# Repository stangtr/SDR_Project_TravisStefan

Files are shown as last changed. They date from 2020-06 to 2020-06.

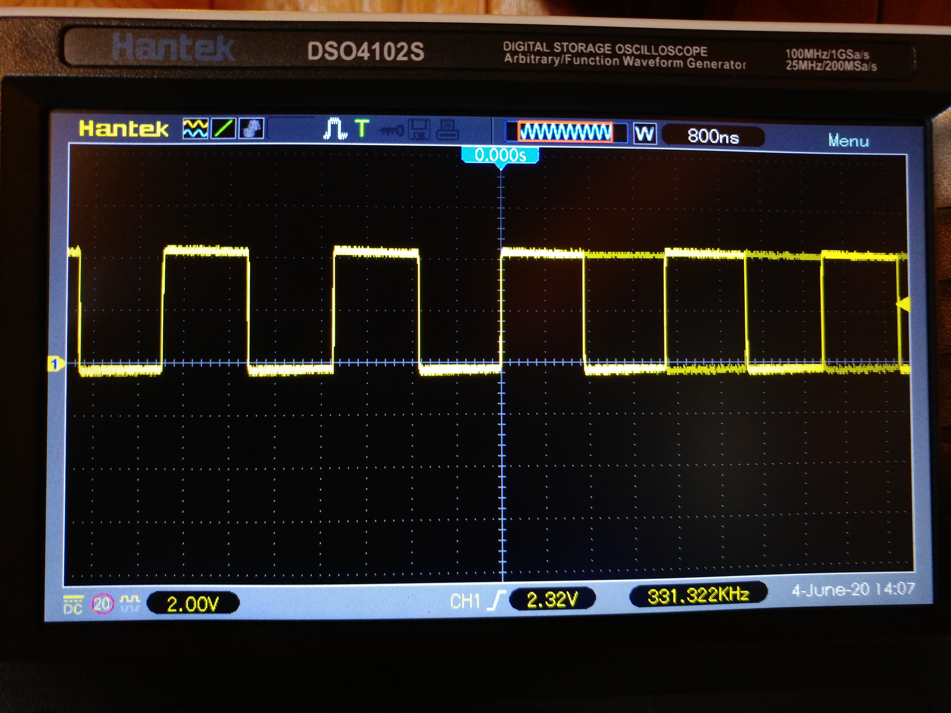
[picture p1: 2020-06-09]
Images/OscilloscopeImages_TravisS/I_LO_NoJumper.jpg

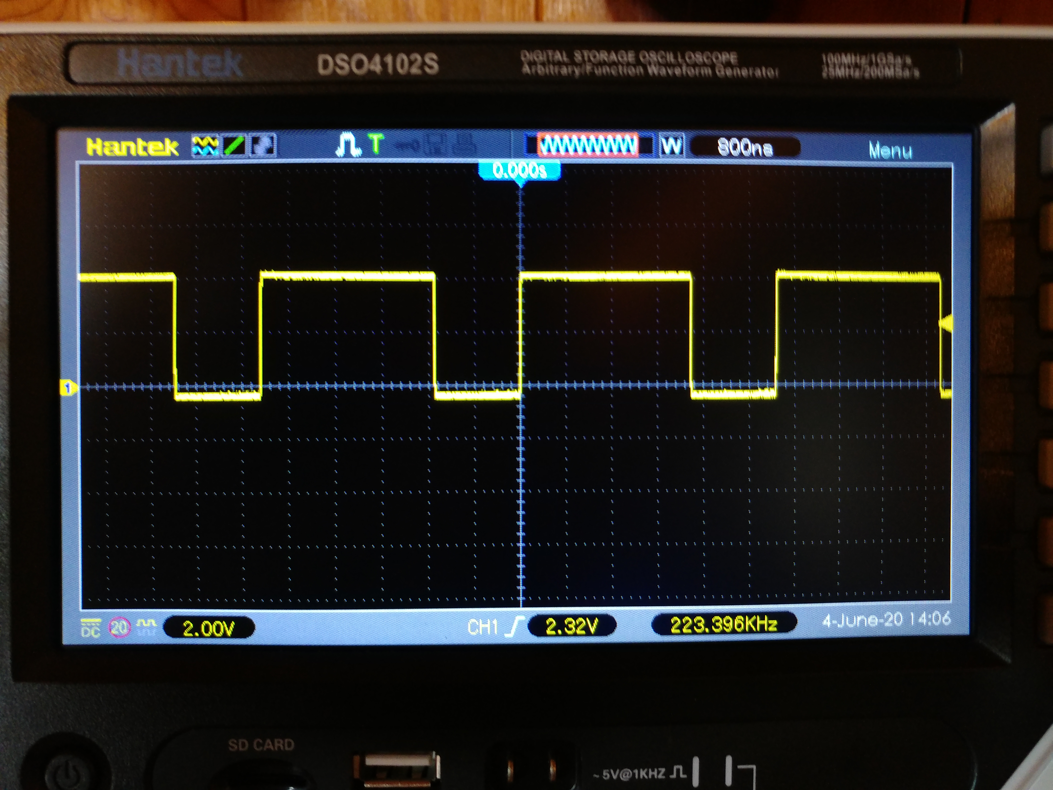
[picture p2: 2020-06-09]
Images/OscilloscopeImages_TravisS/Q_LO_NoJumper.jpg

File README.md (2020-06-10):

# SDR_Project_TravisStefan

## Project Overview
The goal of this project was to design a Software Defined Reciever (SDR) for ENGR 357 Electronics II at Walla Walla University.
Our receiver is designed for the AM frequency range (535kHz - 1605kHz).
Before designing the board in KiCad, we did some simulations in LTSpice to find the correct values for resistors and capacitors, as well as inductors for the band-pass filter (BPF).

## Finished Product
Ideally, the SDR board would have a signal input to the female SMA connector on the input of the BPF. This signal would then be processed and sent to the computer via an auxiliary cable. The correct frequency could be tuned to using the Quisk open radio software. An Arduino is connected to the board for powering the ICs and setting the correct clock output on the Si5351 oscillator IC through communication with Quisk or a short test program. 

## More Documentation
More details can be viewed about the process and the specifications in the wiki tab.

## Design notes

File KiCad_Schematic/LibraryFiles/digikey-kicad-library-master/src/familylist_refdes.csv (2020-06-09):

205 | Embedded - Microcontrollers | U
275 | Motion Sensors - Accelerometers | U
1152 | Magnetic Sensors - Linear, Compass (ICs) | U
69 | TVS - Diodes | D
19 | Fixed Inductors | L
793 | Interface - Controllers | U
1373 | PMIC - Battery Chargers | U
748 | Optical Sensors - Ambient Light, IR, UV Sensors | U
366 | Oscillators | Y
707 | RF Detectors | U
446 | Data Acquisition - Digital Potentiometers | U
533 | Logic - Translators, Level Shifters | U
1324 | Diodes - Bridge Rectifiers | D
740 | USB, DVI, HDMI Connectors | J
1379 | Motion Sensors - IMUs (Inertial Measurement Units) | U
1303 | Barrel - Audio Connectors | CON
628 | Humidity, Moisture Sensors | U
51 | Encoders | S
71 | Alarms, Buzzers, and Sirens | BZ
94 | Tactile Switches | S
968 | Optical Sensors - Photodiodes | PV
120 | Transistors - Bipolar (BJT) - Single | Q
706 | Transistors - Bipolar (BJT) - RF | Q
386 | PMIC - Voltage Regulators - Linear | U
72 | Microphones | MIC
872 | Signal Relays, Up to 2 Amps | RLY
1193 | Memory Connectors - PC Card Sockets | J
40 | Infrared, UV, Visible Emitters | D
655 | Gas Sensors | U
973 | Optical Sensors - Photointerrupters - Slot Type - Logic Output | U
61 | Fuses | F
125 | Transistors - FETs, MOSFETs - Single | Q
79 | Programmable Oscillators | Y
311 | Temperature Sensors - Analog and Digital Output | U
1398 | Automotive Relays | RLY
1400 | Reed Relays | RLY
421 | Logic - Multivibrators | U
127 | Diodes - Rectifiers - Single | D
778 | Diodes - Zener - Single | Z
758 | Diodes - Rectifiers - Arrays | D
210 | Specialized ICs | U
293 | PMIC - Supervisors | U
319 | PMIC - Voltage Reference | VR
747 | Transistors - FETs, MOSFETs - RF | Q
1010 | Transistors - Bipolar (BJT) - Single, Pre-Biased | Q
544 | PMIC - Current Regulation/Management | U
804 | PMIC - Power Management - Specialized | U
1004 | RF Transceiver Modules | MOD
838 | Transistors - FETs, MOSFETs - Arrays | Q
404 | Logic - Buffers, Drivers, Receivers, Transceivers | U
711 | RF Switches | U
122 | Transistors - Bipolar (BJT) - Arrays | Q
1281 | Slide Switches | S
413 | Logic - Gates and Inverters | U
502 | PMIC - Power Distribution Switches, Load Drivers | U
523 | PMIC - Gate Drivers | U
221 | Linear - Amplifiers - Instrumentation, OP Amps, Buffer Amps | U
317 | Linear - Comparators | U
724 | PMIC - LED Drivers | U
388 | Data Acquisition - Digital to Analog Converters (DAC) | U
666 | PMIC - Voltage Regulators - DC DC Switching Regulators | U
865 | TVS - Mixed Technology | TVS
700 | RF Evaluation and Development Kits, Boards | A
1344 | Rotary Potentiometers, Rheostats | POT
871 | Power Relays, Over 2 Amps | RLY
948 | Modular Connectors - Jacks | J
1306 | Coaxial Connectors (RF) | J
944 | Optical Sensors - Photo Detectors - Remote Receiver | U
683 | Ferrite Beads and Chips | FB
441 | LED Indication - Discrete | D
969 | Optical Sensors - Phototransistors | Q
674 | Image Sensors, Camera | U
420 | Interface - Drivers, Receivers, Transceivers | U
100 | Toggle Switches | S
36 | Display Modules - LED Character and Numeric | DS
387 | Data Acquisition - Analog to Digital Converters (ADC) | U
517 | Clock/Timing - Clock Generators, PLLs, Frequency Synthesizers | U
432 | PMIC - Battery Management | U
34 | Battery Holders, Clips, Contacts | BAT
1127 | Surge Suppression ICs | U
438 | PMIC - Voltage Regulators - DC DC Switching Controllers | U
656 | PMIC - Thermal Management | U
1370 | Interface - Analog Switches - Special Purpose | U
789 | PMIC - Voltage Regulators - Special Purpose | U
728 | PMIC - Full, Half-Bridge Drivers | U
422 | Logic - Shift Registers | U
515 | PMIC - V/F and F/V Converters | U
414 | Logic - Flip Flops | U
679 | Linear - Amplifiers - Audio | U
722 | PMIC - Motor Drivers, Controllers | U
767 | Interface - Analog Switches, Multiplexers, Demultiplexers | U
831 | Optoisolators - Transistor, Photovoltaic Output | U
786 | Interface - I/O Expanders | U
1002 | RF Receivers | U
1349 | RF Transceiver ICs | U
691 | Logic - Signal Switches, Multiplexers, Decoders | U
1357 | RFID, RF Access, Monitoring ICs | U
88 | Solid State Relays | RLY
972 | Optical Sensors - Reflective - Analog Output | U
829 | Optoisolators - Logic Output | U
842 | Optoisolators - Triac, SCR Output | U
75 | Balun | T
226 | Clock/Timing - Programmable Timers and Oscillators | U
266 | Clock/Timing - Real Time Clocks | U
668 | PMIC - RMS to DC Converters | U
179 | Pressure Sensors, Transducers | U
552 | Digital Isolators | U
792 | Interface - Sensor and Detector Interfaces | U
1076 | Memory | U
493 | Current Transducers | U
768 | PMIC - AC DC Converters, Offline Switchers | U
800 | PMIC - OR Controllers, Ideal Diodes | Q
7 | Resistor Networks, Arrays | RN
64 | Thyristors - DIACs, SIDACs | D
97 | Pushbutton Switches | S
1140 | Magnetic Sensors - Compass, Magnetic Field (Modules) | U
725 | Navigation Switches, Joystick | S
336 | Thermal Cutoffs (Thermal Fuses) | F
448 | LEDs - Circuit Board Indicators, Arrays, Light Bars, Bar Graphs | D
1315 | Specialized Sensors | U
84 | Accessories | NA
824 | Trimmer Potentiometers | POT
131 | Thyristors - SCRs | D
1325 | Thyristors - TRIACs | TRI
1366 | Magnetic Sensors - Switches (Solid State) | Q
837 | Transistors - JFETs | Q
1003 | RF Transmitters | U
1360 | Addressable, Specialty | D
755 | Rectangular Connectors - Headers, Male Pins | J
947 | Modular Connectors - Jacks With Magnetics | J
913 | Inrush Current Limiters (ICL) | ICL
1230 | Data Acquisition - Touch Screen Controllers | U
1293 | Capacitive Touch Sensors, Proximity Sensor ICs | U
1176 | RF Demodulators | U
223 | DC DC Converters | U
461 | Motion Sensors - Tilt Switches | S
864 | Data Acquisition - ADCs/DACs - Special Purpose | U
1295 | Interface - Modules | U
703 | RF Amplifiers | U
1078 | RF Antennas | ANT
1180 | Sockets for ICs, Transistors | J
1308 | D-Sub Connectors | J
794 | Interface - Specialized | U
1117 | Evaluation Boards - Sensors | A
333 | Evaluation Boards - Embedded - MCU, DSP | A
630 | Display Modules - LCD, OLED, Graphic | DS
365 | Crystal | XTAL
135 | Banana and Tip Connectors - Jacks, Plugs | J
1304 | Barrel - Power Connectors | J
946 | Optical Sensors - Distance Measuring | U
168 | Shunts, Jumpers | J
586 | Test Points | TP
959 | Terminal Blocks - Wire to Board | J

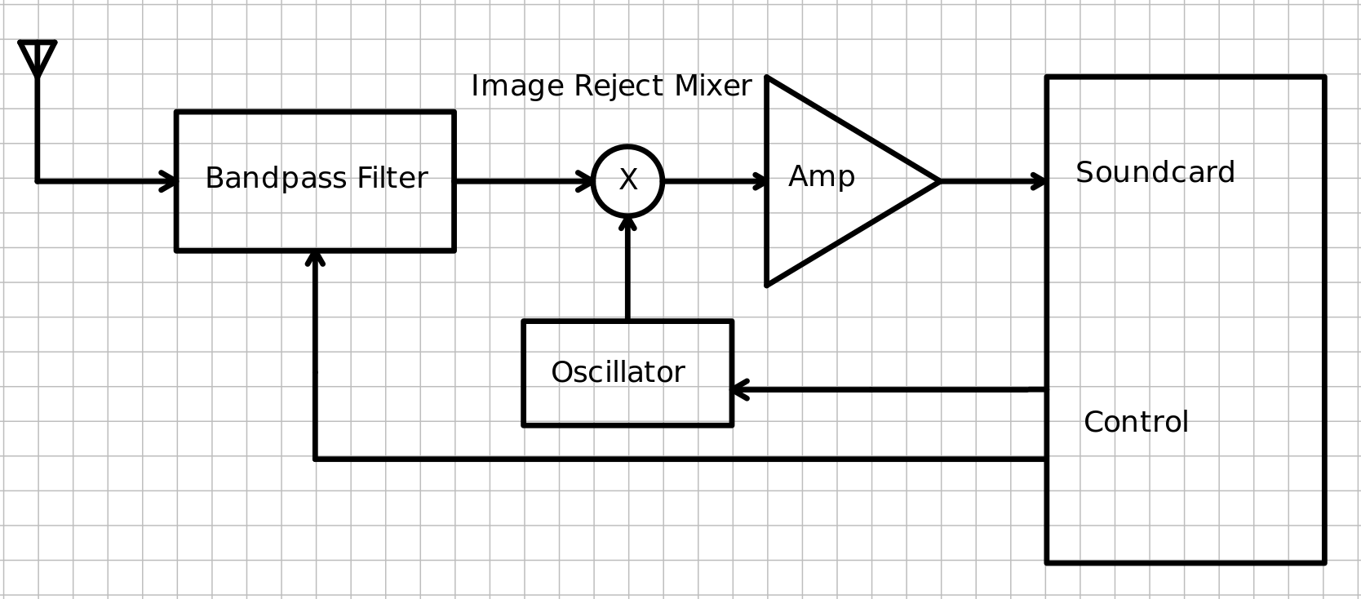
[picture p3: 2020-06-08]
Images/BlockDiagram.png

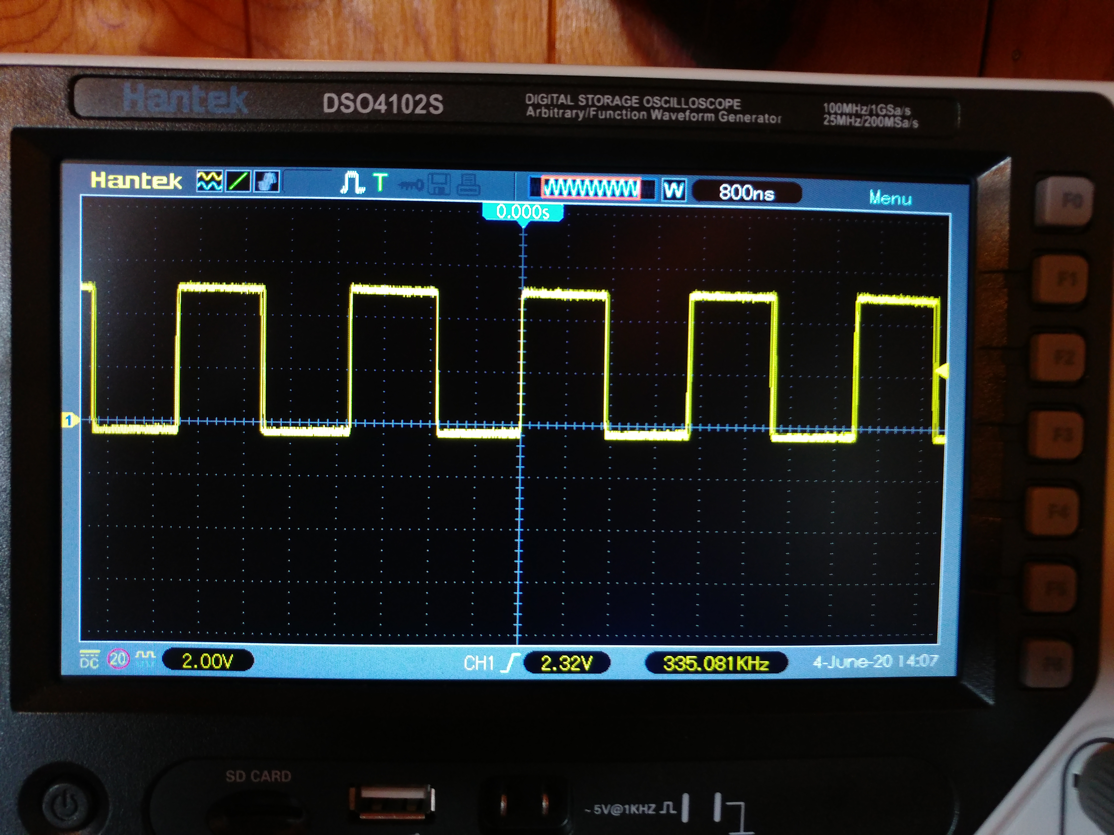
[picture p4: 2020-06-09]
Images/OscilloscopeImages_TravisS/I_LO_WithJumper.jpg

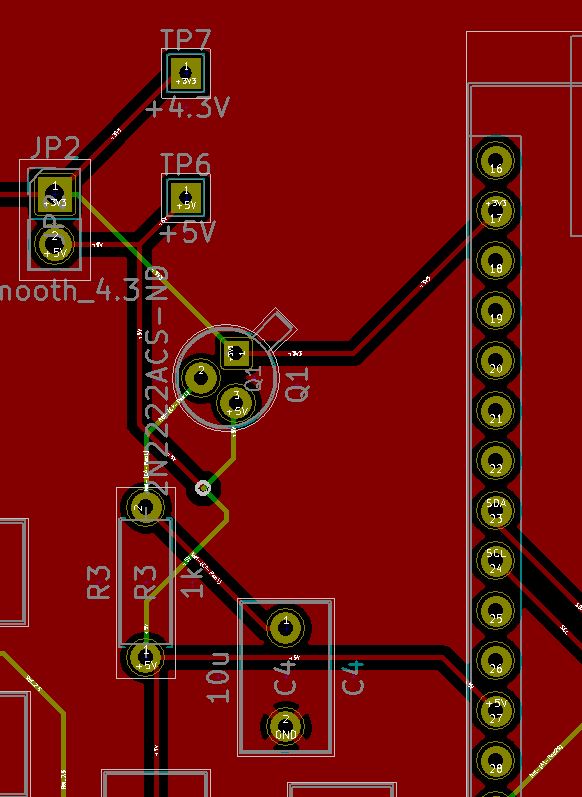
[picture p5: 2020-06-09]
Images/BJT_PCB_Error.JPG

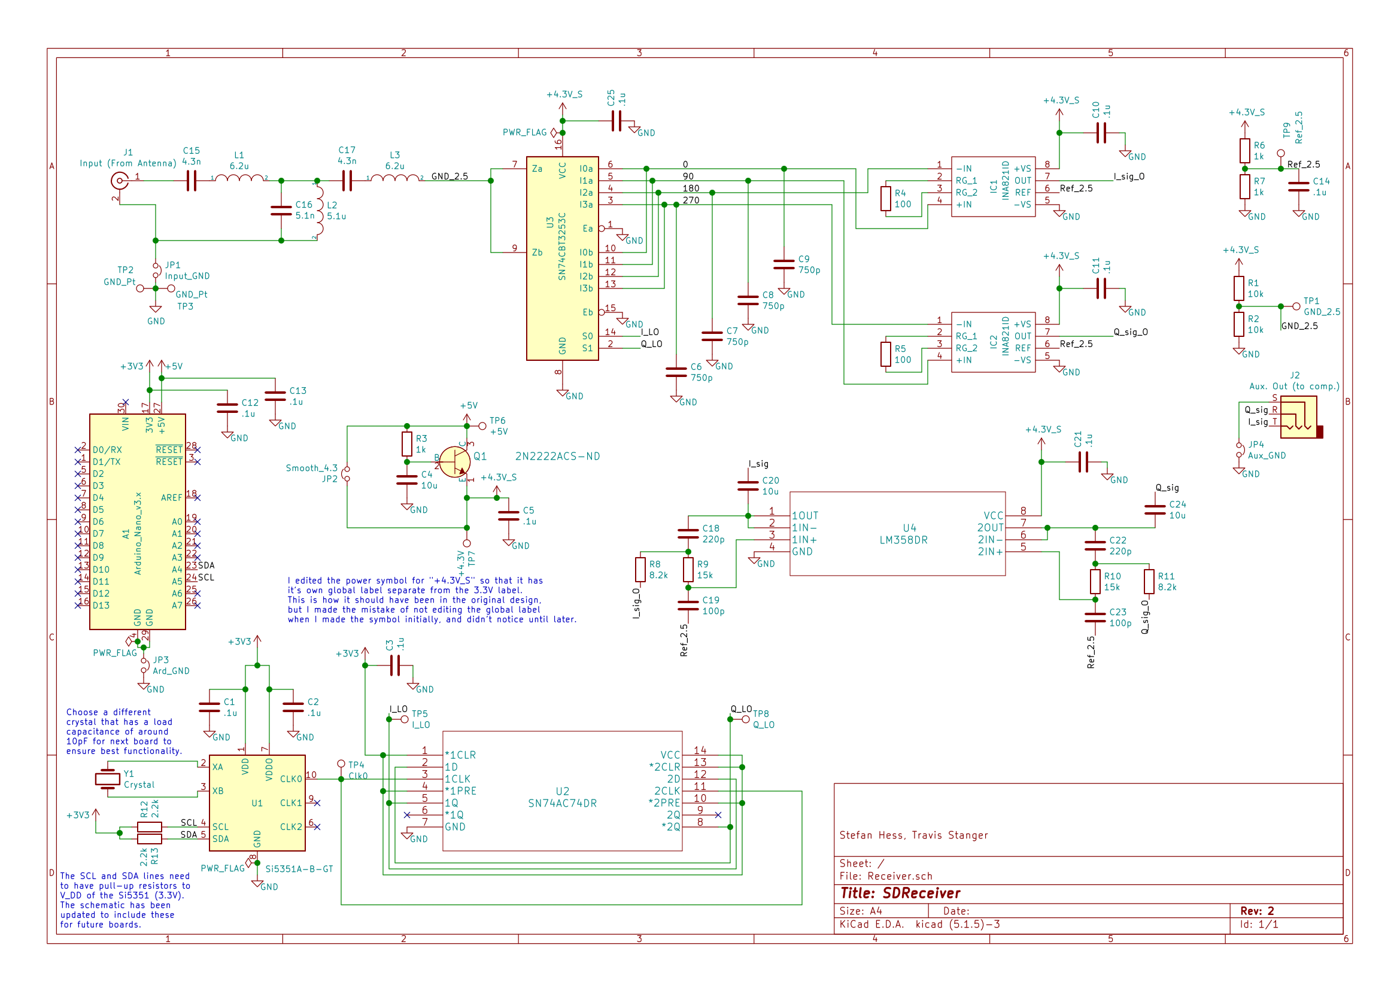
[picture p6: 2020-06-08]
Images/NewReceiver.png

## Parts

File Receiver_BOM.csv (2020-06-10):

Reference | Value | Footprint | Datasheet | Description | Height | Manufacturer_Name | Manufacturer_Part_Number | Mouser Part Number | Mouser Price/Stock
A1 | Arduino_Nano_v3.x | Module:Arduino_Nano | http://www.mouser.com/pdfdocs/Gravitech_Arduino_Nano3_0.pdf
C01 | .1u | Capacitor_THT:C_Disc_D16.0mm_W5.0mm_P10.00mm | http://datasheets.avx.com/SR-Series.pdf
C02 | .1u | Capacitor_THT:C_Disc_D16.0mm_W5.0mm_P10.00mm | http://datasheets.avx.com/SR-Series.pdf
C03 | .1u | Capacitor_THT:C_Disc_D16.0mm_W5.0mm_P10.00mm | http://datasheets.avx.com/SR-Series.pdf
C04 | 10u | Capacitor_THT:C_Disc_D7.5mm_W4.4mm_P5.00mm | https://www.digikey.com/en/datasheets/tdk-corporation/tdk-corporation-leadmlcc-conventional-fk-en
C05 | .1u | Capacitor_THT:C_Disc_D16.0mm_W5.0mm_P10.00mm | http://datasheets.avx.com/SR-Series.pdf
C06 | 750p | Capacitor_THT:C_Disc_D7.5mm_W5.0mm_P7.50mm | https://www.nteinc.com/capacitor_web/pdf/90000.pdf
C07 | 750p | Capacitor_THT:C_Disc_D7.5mm_W5.0mm_P7.50mm | https://www.nteinc.com/capacitor_web/pdf/90000.pdf
C08 | 750p | Capacitor_THT:C_Disc_D7.5mm_W5.0mm_P7.50mm | https://www.nteinc.com/capacitor_web/pdf/90000.pdf
C09 | 750p | Capacitor_THT:C_Disc_D7.5mm_W5.0mm_P7.50mm | https://www.nteinc.com/capacitor_web/pdf/90000.pdf
C10 | .1u | Capacitor_THT:C_Disc_D16.0mm_W5.0mm_P10.00mm | http://datasheets.avx.com/SR-Series.pdf
C11 | .1u | Capacitor_THT:C_Disc_D16.0mm_W5.0mm_P10.00mm | http://datasheets.avx.com/SR-Series.pdf
C12 | .1u | Capacitor_THT:C_Disc_D16.0mm_W5.0mm_P10.00mm | http://datasheets.avx.com/SR-Series.pdf
C13 | .1u | Capacitor_THT:C_Disc_D16.0mm_W5.0mm_P10.00mm | http://datasheets.avx.com/SR-Series.pdf
C14 | .1u | Capacitor_THT:C_Disc_D16.0mm_W5.0mm_P10.00mm | http://datasheets.avx.com/SR-Series.pdf
C15 | 4.3n | Capacitor_SMD:C_0603_1608Metric_Pad1.05x0.95mm_HandSolder | https://search.murata.co.jp/Ceramy/image/img/A01X/G101/ENG/GRM1887U1H432JA01-01.pdf
C16 | 5.1n | Capacitor_SMD:C_0603_1608Metric_Pad1.05x0.95mm_HandSolder | https://search.murata.co.jp/Ceramy/image/img/A01X/G101/ENG/GRM1887U1H512JA01-01.pdf
C17 | 4.3n | Capacitor_SMD:C_0603_1608Metric_Pad1.05x0.95mm_HandSolder | https://search.murata.co.jp/Ceramy/image/img/A01X/G101/ENG/GRM1887U1H432JA01-01.pdf
C18 | 220p | Capacitor_THT:C_Disc_D7.5mm_W5.0mm_P7.50mm | https://content.kemet.com/datasheets/KEM_C1049_GOLDMAX_C0G.pdf
C19 | 100p | Capacitor_THT:C_Disc_D7.5mm_W5.0mm_P7.50mm | https://content.kemet.com/datasheets/KEM_C1049_GOLDMAX_C0G.pdf
C20 | 10u | Capacitor_THT:C_Disc_D7.5mm_W4.4mm_P5.00mm | https://www.digikey.com/en/datasheets/tdk-corporation/tdk-corporation-leadmlcc-conventional-fk-en
C21 | .1u | Capacitor_THT:C_Disc_D16.0mm_W5.0mm_P10.00mm | http://datasheets.avx.com/SR-Series.pdf
C22 | 220p | Capacitor_THT:C_Disc_D7.5mm_W5.0mm_P7.50mm | https://content.kemet.com/datasheets/KEM_C1049_GOLDMAX_C0G.pdf
C23 | 100p | Capacitor_THT:C_Disc_D7.5mm_W5.0mm_P7.50mm | https://content.kemet.com/datasheets/KEM_C1049_GOLDMAX_C0G.pdf
C24 | 10u | Capacitor_THT:C_Disc_D7.5mm_W4.4mm_P5.00mm | https://www.digikey.com/en/datasheets/tdk-corporation/tdk-corporation-leadmlcc-conventional-fk-en
C25 | .1u | Capacitor_THT:C_Disc_D16.0mm_W5.0mm_P10.00mm | http://datasheets.avx.com/SR-Series.pdf
IC1 | INA821ID | digikey-footprints:SOIC-8_W3.9mm | http://www.ti.com/lit/ds/symlink/ina821.pdf | Instrumentation Amplifiers Precision Low Power INA | 1.75 | Texas Instruments | INA821ID | 595-INA821ID | https://www.mouser.com/Search/Refine.aspx?Keyword=595-INA821ID
IC2 | INA821ID | digikey-footprints:SOIC-8_W3.9mm | http://www.ti.com/lit/ds/symlink/ina821.pdf | Instrumentation Amplifiers Precision Low Power INA | 1.75 | Texas Instruments | INA821ID | 595-INA821ID | https://www.mouser.com/Search/Refine.aspx?Keyword=595-INA821ID
J1 | Input (From Antenna) | Connector_Coaxial:SMA_Molex_73251-1153_EdgeMount_Horizontal | ~
J2 | Aux. Out (to comp.) | Connector_Audio:Jack_3.5mm_Switronic_ST-005-G_horizontal | ~
JP1 | Input_GND | Connector_PinHeader_2.54mm:PinHeader_1x02_P2.54mm_Vertical | ~
JP2 | Smooth_4.3 | Connector_PinHeader_2.54mm:PinHeader_1x02_P2.54mm_Vertical | ~
JP3 | Ard_GND | Connector_PinHeader_2.54mm:PinHeader_1x02_P2.54mm_Vertical | ~
JP4 | Aux_GND | Connector_PinHeader_2.54mm:PinHeader_1x02_P2.54mm_Vertical | ~
L1 | 6.2u | Inductor_THT:L_Toroid_Vertical_L10.0mm_W5.0mm_P5.08mm | http://www.lodestonepacific.com/distrib/pdfs/Micrometals/RFA_Cat.pdf
L2 | 5.1u | Inductor_THT:L_Toroid_Vertical_L10.0mm_W5.0mm_P5.08mm | http://www.lodestonepacific.com/distrib/pdfs/Micrometals/RFA_Cat.pdf
L3 | 6.2u | Inductor_THT:L_Toroid_Vertical_L10.0mm_W5.0mm_P5.08mm | http://www.lodestonepacific.com/distrib/pdfs/Micrometals/RFA_Cat.pdf
Q1 | 2N2222ACS-ND | digikey-footprints:TO-18-3 | https://my.centralsemi.com/get_document.php?cmp=1&mergetype=pd&mergepath=pd&pdf_id=2N2221A.PDF
R01 | 10k | Resistor_THT:R_Axial_DIN0207_L6.3mm_D2.5mm_P7.62mm_Horizontal | ~
R02 | 10k | Resistor_THT:R_Axial_DIN0207_L6.3mm_D2.5mm_P7.62mm_Horizontal | ~
R03 | 1k | Resistor_THT:R_Axial_DIN0207_L6.3mm_D2.5mm_P7.62mm_Horizontal | ~
R04 | 100 | Resistor_THT:R_Axial_DIN0207_L6.3mm_D2.5mm_P7.62mm_Horizontal | ~
R05 | 100 | Resistor_THT:R_Axial_DIN0207_L6.3mm_D2.5mm_P7.62mm_Horizontal | ~
R06 | 1k | Resistor_THT:R_Axial_DIN0207_L6.3mm_D2.5mm_P7.62mm_Horizontal | ~
R07 | 1k | Resistor_THT:R_Axial_DIN0207_L6.3mm_D2.5mm_P7.62mm_Horizontal | ~
R08 | 8.2k | Resistor_THT:R_Axial_DIN0207_L6.3mm_D2.5mm_P7.62mm_Horizontal | ~
R09 | 15k | Resistor_THT:R_Axial_DIN0207_L6.3mm_D2.5mm_P7.62mm_Horizontal | ~
R10 | 15k | Resistor_THT:R_Axial_DIN0207_L6.3mm_D2.5mm_P7.62mm_Horizontal | ~
R11 | 8.2k | Resistor_THT:R_Axial_DIN0207_L6.3mm_D2.5mm_P7.62mm_Horizontal | ~
R12 | 2.2k | Resistor_THT:R_Axial_DIN0207_L6.3mm_D2.5mm_P7.62mm_Horizontal | ~
R13 | 2.2k | Resistor_THT:R_Axial_DIN0207_L6.3mm_D2.5mm_P7.62mm_Horizontal | ~
TP1 | GND_2.5 | TestPoint:TestPoint_THTPad_1.5x1.5mm_Drill0.7mm | ~
TP2 | GND_Pt | TestPoint:TestPoint_THTPad_1.5x1.5mm_Drill0.7mm | ~
TP3 | GND_Pt | TestPoint:TestPoint_THTPad_1.5x1.5mm_Drill0.7mm | ~
TP4 | Clk0 | TestPoint:TestPoint_THTPad_1.5x1.5mm_Drill0.7mm | ~
TP5 | I_LO | TestPoint:TestPoint_THTPad_1.5x1.5mm_Drill0.7mm | ~
TP6 | +5V | TestPoint:TestPoint_THTPad_1.5x1.5mm_Drill0.7mm | ~
TP7 | +4.3V | TestPoint:TestPoint_THTPad_1.5x1.5mm_Drill0.7mm | ~
TP8 | Q_LO | TestPoint:TestPoint_THTPad_1.5x1.5mm_Drill0.7mm | ~
TP9 | Ref_2.5 | TestPoint:TestPoint_THTPad_1.5x1.5mm_Drill0.7mm | ~
U1 | Si5351A-B-GT | Package_SO:MSOP-10_3x3mm_P0.5mm | https://www.silabs.com/documents/public/data-sheets/Si5351-B.pdf
U2 | SN74AC74DR | digikey-footprints:SOIC-14_W3.9mm | https://www.ti.com/lit/ds/symlink/sn74ac74.pdf
U3 | SN74CBT3253C | Package_SO:SOIC-16_3.9x9.9mm_P1.27mm | https://www.ti.com/lit/ds/symlink/sn74cbt3253c.pdf?ts=1587934047839
U4 | LM358DR | digikey-footprints:SOIC-8_W3.9mm | https://www.ti.com/lit/ds/symlink/lm358.pdf?HQS=TI-null-null-digikeymode-df-pf-null-wwe
Y1 | Crystal | Crystal:Crystal_HC49-U_Vertical | http://www.raltron.com/wp-content/uploads/2016/12/AS-SERIES.pdf

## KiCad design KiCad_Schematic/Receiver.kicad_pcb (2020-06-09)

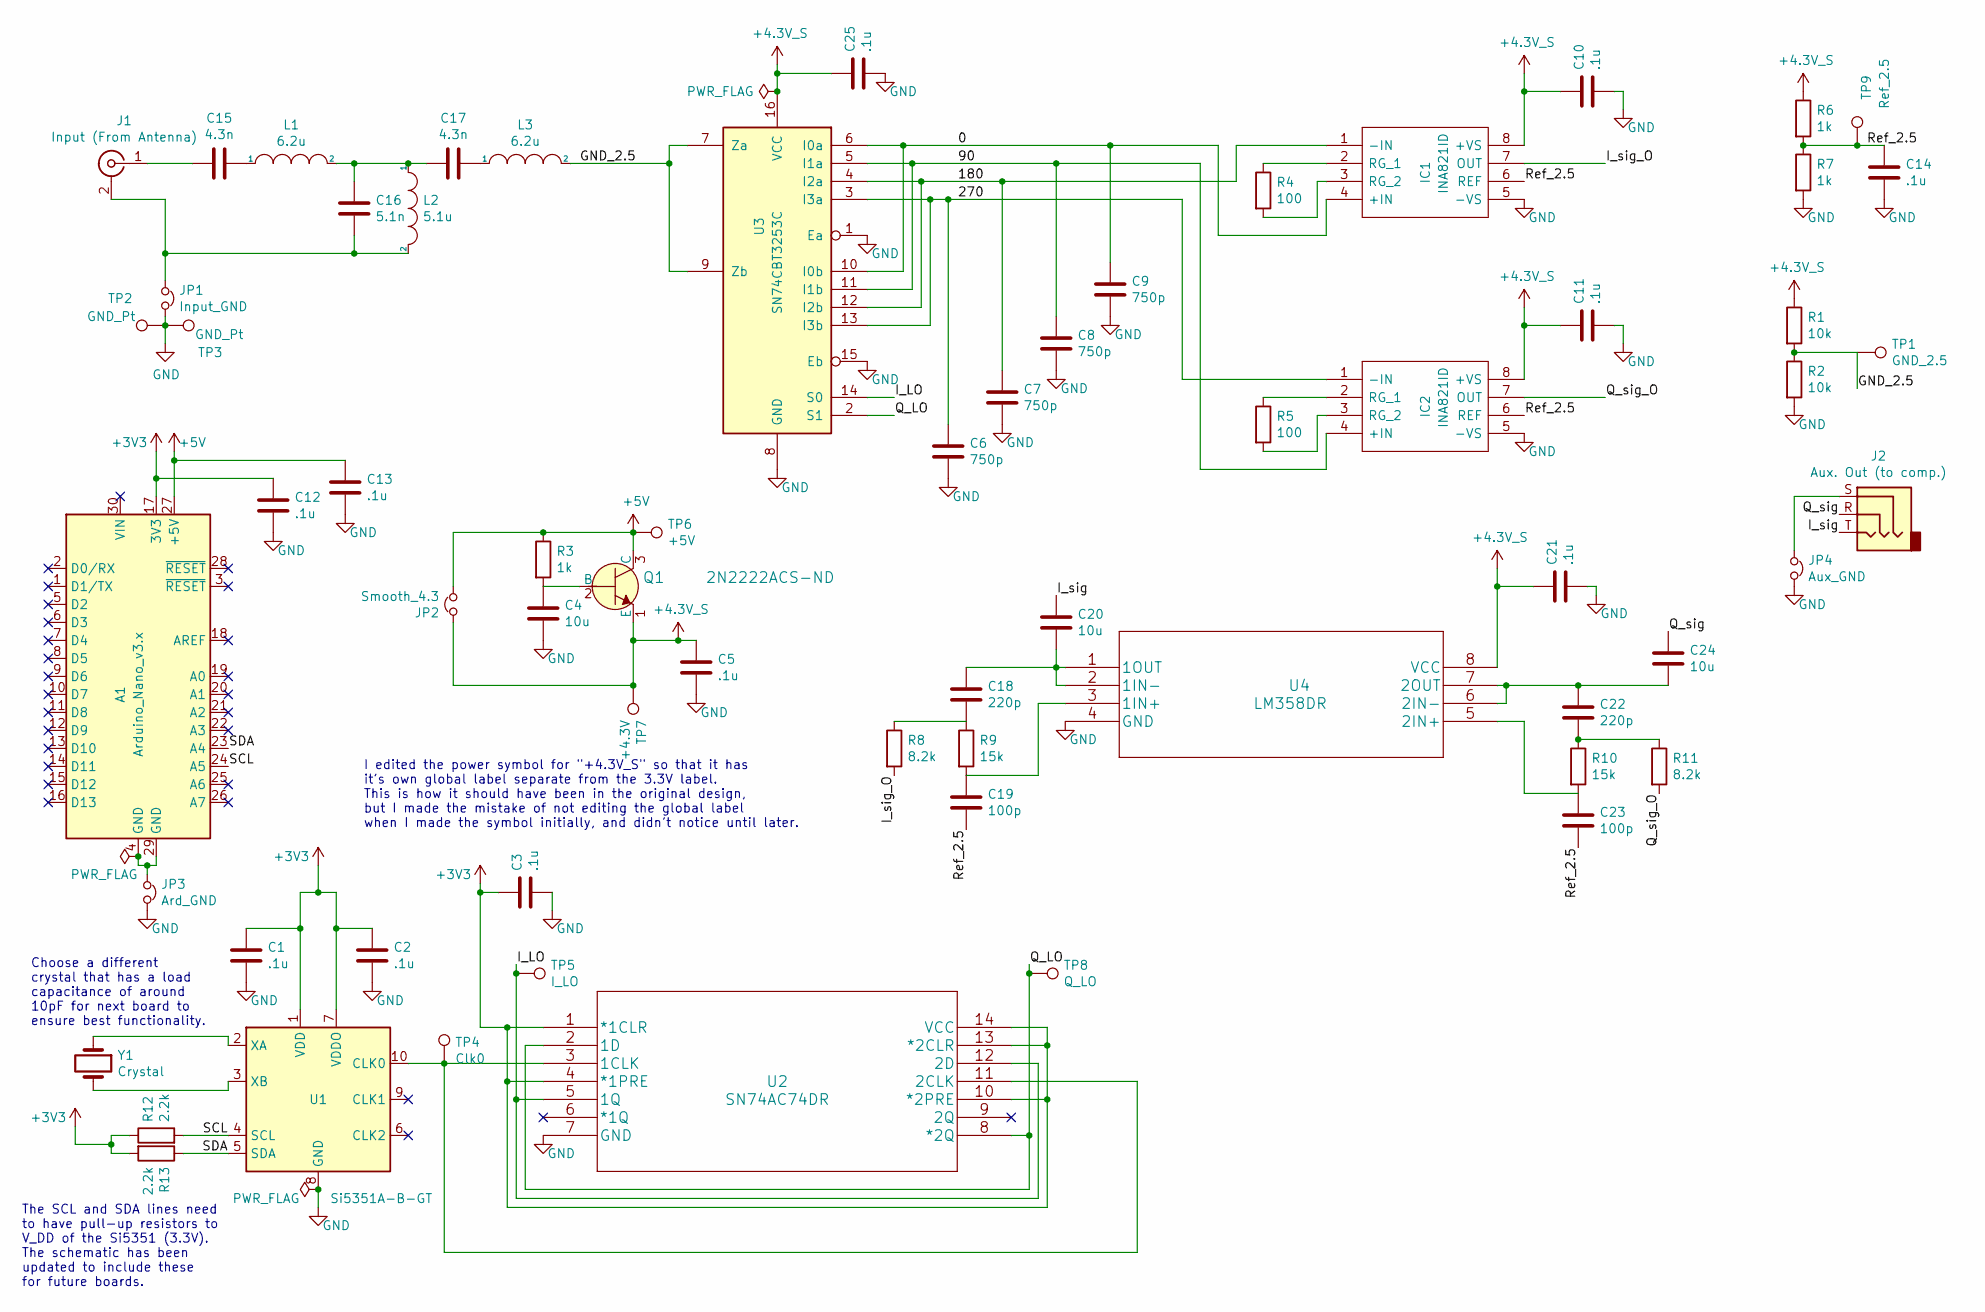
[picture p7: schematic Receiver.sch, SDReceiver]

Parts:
A1: Arduino_Nano_v3.x; Arduino_Nano
C1, C2, C3, C5, C10, C11, C12, C13, C14, C21, C25: .1u; C_Disc_D16.0mm_W5.0mm_P10.00mm
C4, C20, C24: 10u; C_Disc_D7.5mm_W4.4mm_P5.00mm
C6, C7, C8, C9: 750p; C_Disc_D7.5mm_W5.0mm_P7.50mm
C15, C17: 4.3n; C_0603_1608Metric_Pad1.05x0.95mm_HandSolder
C16: 5.1n; C_0603_1608Metric_Pad1.05x0.95mm_HandSolder
C18, C22: 220p; C_Disc_D7.5mm_W5.0mm_P7.50mm
C19, C23: 100p; C_Disc_D7.5mm_W5.0mm_P7.50mm
IC1, IC2: INA821ID; SOIC-8_W3.9mm; Mouser Part Number 595-INA821ID
J1: Input (From Antenna); SMA_Molex_73251-1153_EdgeMount_Horizontal
J2: Aux. Out (to comp.); Jack_3.5mm_Switronic_ST-005-G_horizontal
JP1: Input_GND; PinHeader_1x02_P2.54mm_Vertical
JP2: Smooth_4.3; PinHeader_1x02_P2.54mm_Vertical
JP3: Ard_GND; PinHeader_1x02_P2.54mm_Vertical
JP4: Aux_GND; PinHeader_1x02_P2.54mm_Vertical
L1, L3: 6.2u; L_Toroid_Vertical_L10.0mm_W5.0mm_P5.08mm
L2: 5.1u; L_Toroid_Vertical_L10.0mm_W5.0mm_P5.08mm
Q1: 2N2222ACS-ND; TO-18-3
R1, R2: 10k; R_Axial_DIN0207_L6.3mm_D2.5mm_P7.62mm_Horizontal
R3, R6, R7: 1k; R_Axial_DIN0207_L6.3mm_D2.5mm_P7.62mm_Horizontal
R4, R5: 100; R_Axial_DIN0207_L6.3mm_D2.5mm_P7.62mm_Horizontal
R8, R11: 8.2k; R_Axial_DIN0207_L6.3mm_D2.5mm_P7.62mm_Horizontal
R9, R10: 15k; R_Axial_DIN0207_L6.3mm_D2.5mm_P7.62mm_Horizontal
R12, R13: 2.2k; R_Axial_DIN0207_L6.3mm_D2.5mm_P7.62mm_Horizontal
TP1: GND_2.5; TestPoint_THTPad_1.5x1.5mm_Drill0.7mm
TP2, TP3: GND_Pt; TestPoint_THTPad_1.5x1.5mm_Drill0.7mm
TP4: Clk0; TestPoint_THTPad_1.5x1.5mm_Drill0.7mm
TP5: I_LO; TestPoint_THTPad_1.5x1.5mm_Drill0.7mm
TP6: +5V; TestPoint_THTPad_1.5x1.5mm_Drill0.7mm
TP7: +4.3V; TestPoint_THTPad_1.5x1.5mm_Drill0.7mm
TP8: Q_LO; TestPoint_THTPad_1.5x1.5mm_Drill0.7mm
TP9: Ref_2.5; TestPoint_THTPad_1.5x1.5mm_Drill0.7mm
U1: Si5351A-B-GT; MSOP-10_3x3mm_P0.5mm
U2: SN74AC74DR; SOIC-14_W3.9mm
U3: SN74CBT3253C; SOIC-16_3.9x9.9mm_P1.27mm
U4: LM358DR; SOIC-8_W3.9mm
Y1: Crystal; Crystal_HC49-U_Vertical

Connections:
+3V3: A1.17 (3V3), C1.1, C2.1, C3.1, C12.1, R12.1, R13.2, U1.1 (VDD), U1.7 (VDDO), U2.1 (*1CLR), U2.4 (*1PRE), U2.10 (*2PRE), U2.13 (*2CLR), U2.14 (VCC)
+4.3V_S: C5.1, C10.1, C11.1, C21.1, C25.1, IC1.8 (+VS), IC2.8 (+VS), JP2.1, Q1.1 (E), R1.1, R6.1, TP7.1, U3.16 (VCC), U4.8 (VCC)
+5V: A1.27 (+5V), C13.1, JP2.2, Q1.3 (C), R3.1, TP6.1
/0: C9.1, IC1.4 (+IN), U3.6 (I0a), U3.10 (I0b)
/90: C8.1, IC2.4 (+IN), U3.5 (I1a), U3.11 (I1b)
/180: C7.1, IC1.1 (-IN), U3.4 (I2a), U3.12 (I2b)
/270: C6.1, IC2.1 (-IN), U3.3 (I3a), U3.13 (I3b)
/GND_2.5: L3.2, R1.2, R2.1, TP1.1, U3.7 (Za), U3.9 (Zb)
/I_LO: TP5.1, U2.5 (1Q), U2.12 (2D), U3.14 (S0)
/I_sig: C20.1, J2.T
/I_sig_O: IC1.7 (OUT), R8.2
/Q_LO: TP8.1, U2.2 (1D), U2.8 (*2Q), U3.2 (S1)
/Q_sig: C24.1, J2.R
/Q_sig_O: IC2.7 (OUT), R11.2
/Ref_2.5: C14.1, C19.2, C23.2, IC1.6 (REF), IC2.6 (REF), R6.2, R7.1, TP9.1
/SCL: A1.24 (A5), R12.2, U1.4 (SCL)
/SDA: A1.23 (A4), R13.1, U1.5 (SDA)
GND: C1.2, C2.2, C3.2, C4.2, C5.2, C6.2, C7.2, C8.2, C9.2, C10.2, C11.2, C12.2, C13.2, C14.2, C21.2, C25.2, IC1.5 (-VS), IC2.5 (-VS), JP1.2, JP3.2, JP4.2, R2.2, R7.2, TP2.1, TP3.1, U1.8 (GND), U2.7 (GND), U3.1 (Ea), U3.8 (GND), U3.15 (Eb), U4.4 (GND)
unnamed: A1.4 (GND), A1.29 (GND), JP3.1
unnamed: C4.1, Q1.2 (B), R3.2
unnamed: C15.1, L1.1
unnamed: C15.2, J1.1 (In)
unnamed: C16.1, J1.2 (Ext), JP1.1, L2.2
unnamed: C16.2, C17.1, L1.2, L2.1
unnamed: C17.2, L3.1
unnamed: C18.1, C20.2, U4.1 (1OUT), U4.2 (1IN-)
unnamed: C18.2, R8.1, R9.1
unnamed: C19.1, R9.2, U4.3 (1IN+)
unnamed: C22.1, C24.2, U4.6 (2IN-), U4.7 (2OUT)
unnamed: C22.2, R10.1, R11.1
unnamed: C23.1, R10.2, U4.5 (2IN+)
unnamed: IC1.2 (RG_1), R4.1
unnamed: IC1.3 (RG_2), R4.2
unnamed: IC2.2 (RG_1), R5.1
unnamed: IC2.3 (RG_2), R5.2
unnamed: J2.S, JP4.1
unnamed: TP4.1, U1.10 (CLK0), U2.3 (1CLK), U2.11 (2CLK)
unnamed: U1.2 (XA), Y1.1
unnamed: U1.3 (XB), Y1.2

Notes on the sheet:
Choose a different crystal that has a load capacitance of around 10pF for next board to ensure best functionality.
The SCL and SDA lines need to have pull-up resistors to V_DD of the Si5351 (3.3V). The schematic has been updated to include these for future boards.
I edited the power symbol for "+4.3V_S" so that it has it's own global label separate from the 3.3V label. This is how it should have been in the original design, but I made the mistake of not editing the global label when I made the symbol initially, and didn't notice until later.

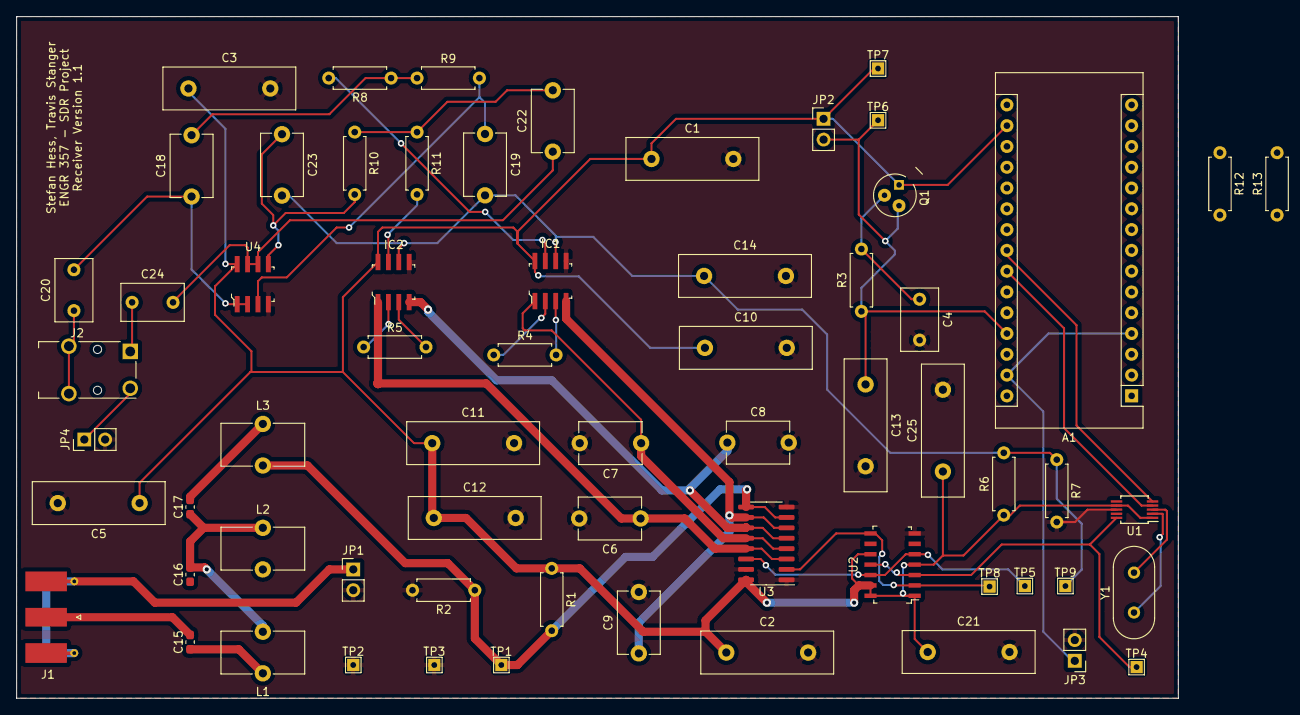
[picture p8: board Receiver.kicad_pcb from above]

Board: 2 copper layers, 142.0 x 83.3 mm, 65 parts (0 on the bottom side), 39 nets.

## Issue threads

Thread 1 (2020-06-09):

4.3V and 3.3V Buses Connected

stangtr, 2020-06-09:
I noticed that when routing the PCB in KiCad, the 3.3V pin of the Arduino was connected to where the 4.3V_S reference (and pin 1 of the transistor) was. I originally didn't think it was an issue, since I thought that everything looked fine in the schematic. After testing a couple parts of the board, I looked back at my schematic and realized that I had edited a "3.3V" power symbol to be "4.3V_S" with the same 3.3V global label.

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

stangtr, 2020-06-09:
I fixed this issue in the schematic, so the schematic on this repository for future boards will not have this issue as long as the PCB is _completely_ re-routed.

Closed 2020-06-09.

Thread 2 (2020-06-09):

Didn't add Pull-up Resistors on SDA and SCL Lines on the PCB

stangtr, 2020-06-09:
We did not initially notice in the datasheet for the Si5351 oscillator that there were supposed to be pull-up resistors to V<sub>DD</sub> of the oscillator IC. To temporarily fix the issue, we soldered a 2.2 k&#937; resistor from A4 and another from A5 to the 3.3V pin of the Arduino as shown below.
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

stangtr, 2020-06-09:
This issue has been fixed on the schematic in this repository so that it doesn't happen in future revisions of the board.

Closed 2020-06-09.

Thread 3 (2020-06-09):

Forgot to Connect Pad 6 of IC1

stangtr, 2020-06-09:
In routing the PCB in KiCad, I forgot to finish routing the trace to pad 6 of IC1 (an instrumentation amp). This would inhibit the signal flow of I_Sig_O into the low-pass filter op amp since the reference on the instrumentation amp would most likely then be 0. This is not a schematic issue, but rather one that shows that you should pay careful attention to the error messages when routing and checking your PCB layout.

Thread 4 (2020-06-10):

0.1uF Capacitor Footprints Bigger than Necessary

stangtr, 2020-06-10:
The 0.1uF capacitors were assigned larger footprints than necessary. The footprints for these capacitors could be changed to the same footprint as the 10uF capacitors (C4, C20, and C24 on schematic) to allow for a smaller PCB in the future.

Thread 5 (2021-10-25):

Please update https://github.com/stangtr/SDR_Project_TravisStefan/wiki/Building-Instructions

sethhillbrand, 2021-10-25:
The site `kicad-pcb.org` is no longer controlled by the KiCad project

https://forum.kicad.info/t/warning-avoid-all-links-to-kicad-pcb-org-use-kicad-org/31521

Closed 2022-01-15.

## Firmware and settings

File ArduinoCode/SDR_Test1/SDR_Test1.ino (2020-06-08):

#include "si5351.h"
#include "Wire.h"

Si5351 si5351;

void setup()
{
  bool i2c_found;
  i2c_found = si5351.init(SI5351_CRYSTAL_LOAD_10PF, 0, 0);
  si5351.set_freq(4*100000000ULL, SI5351_CLK0);
  Serial.begin(115200);
}


void loop()
{
  si5351.update_status();
  Serial.print("SYS_INIT: ");
  Serial.print(si5351.dev_status.SYS_INIT);
  Serial.print("  LOL_A: ");
  Serial.print(si5351.dev_status.LOL_A);
  Serial.print("  LOL_B: ");
  Serial.print(si5351.dev_status.LOL_B);
  Serial.print("  LOS: ");
  Serial.print(si5351.dev_status.LOS);
  Serial.print("  REVID: ");
  Serial.println(si5351.dev_status.REVID);
}

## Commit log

2020-06-08 Added New Schematic Picture
2020-06-08 Added Arduino Code
2020-06-09 Added KiCad Files and Libraries
    [Receiver.kicad_pcb, Receiver.sch, familylist_refdes.csv]
2020-06-09 Added PCB and Oscilloscope Images
2020-06-10 Added BOM in the awesome flavors of csv and ods!
    [Receiver_BOM.csv, Receiver_BOM.ods]
